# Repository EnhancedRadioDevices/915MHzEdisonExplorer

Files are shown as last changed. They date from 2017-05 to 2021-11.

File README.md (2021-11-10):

# 915MHz RF Explorer block

This Edison Block makes use of a TI CC1110 RF transciever to allow a connected Edison to communicate on the 915MHz band. It is also capable of transmitting at 868MHz (a small antenna alteration will make it much more efficient at that band).

The 915MHz Edison Explorer Block allows an Intel Edison to serve as a bridge from WiFi or Bluetooth to a 915MHz protocol, such as Z-wave, Zigbee, or other manufacturer specific protocols.

# Using these files

The files in this repo are for the 915MHz Explorer hardware. To open them, you'll need KiCAD:

- http://kicad.org/

It may also be helpful to use these libraries:

- https://github.com/mogar/KiCAD_libs

# Applications

For use with Z-wave, 6LowPan, etc.

For Smart Meters, see Wireless-M bus: http://www.ti.com/tool/wmbus

# Supporting Software

For the firmware that goes on the CC1110 itself, see:

- https://github.com/EnhancedRadioDevices/subg_rfspy

For the software that runs on the Edison to communicate with the CC1110, see :

- https://github.com/EnhancedRadioDevices/spi_serial

We also have an RFCat port available

- https://github.com/EnhancedRadioDevices/rfcat

# Acquiring hardware

The Explorer block is currently for sale:

- https://enhanced-radio-devices.myshopify.com/collections/900mhz-explorer-block

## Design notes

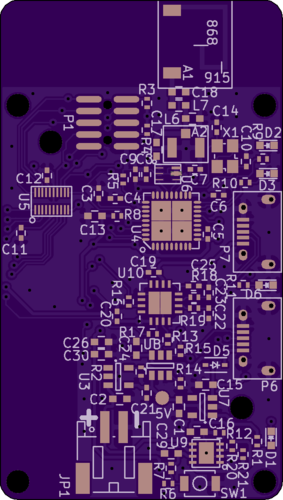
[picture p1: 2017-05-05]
EdisonBlock_915MHz_fab/EdisonBlock_915MHz_bottom.png

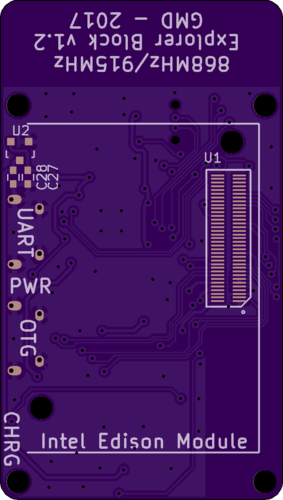
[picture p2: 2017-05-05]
EdisonBlock_915MHz_fab/EdisonBlock_915MHz_top.png

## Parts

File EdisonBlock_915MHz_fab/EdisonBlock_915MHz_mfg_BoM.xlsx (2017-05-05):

Id | Designator | Package | Quantity | Description | Supplier | Part Number
1 | A1 | 0915AT43A0026E | 1 | 0915AT43A0026E | DigiKey | 712-1535-1-ND
2 | A2 | 1909763-1 | 1 | 1909763-1 | DigiKey | A118077CT-ND
3 | C10,C14 | C_0402 | 2 | 18p | DigiKey | 490-5858-1-ND
4 | C13,C1,C2,C15,C16,C24,C26,C29,C30 | C_0603 | 9 | 4.7u | DigiKey | 1276-1045-6-ND
5 | C17 | C_0603 | 1 | 100p | DigiKey | 720-1325-1-ND
6 | C18 | C_0603 | 1 | 0.5p | DigiKey | 1276-1818-1-ND
7 | C22,C23 | C_0402 | 2 | 47p | DigiKey | 490-6241-1-ND
8 | C27,C28 | C_0603 | 2 | DNP
9 | C3 | C_0402 | 1 | 1u | DigiKey | 490-3890-1-ND
10 | C4,C5,C11,C12,C19,C20,C21,C25 | C_0402 | 8 | 0.1u | DigiKey | 490-6328-1-ND
11 | C6,C8 | C_0402 | 2 | 10n | DigiKey | 490-4516-1-ND
12 | C7 | C_0402 | 1 | 2p2 | DigiKey | 490-5932-1-ND
13 | C9 | C_0402 | 1 | 220p | DigiKey | 490-1293-1-ND
14 | D1,D2,D6 | LED_0603 | 3 | RED | DigiKey | 160-1436-1-ND
15 | D3 | LED_0603 | 1 | GREEN | DigiKey | 160-1446-2-ND
16 | D5 | SOD-323 | 1 | DNP
17 | JP1 | JST_ACH_BM02B-ACHSS_02x1.20mm_Angled | 1 | M02JST-PTH-2 | DigiKey | 455-1749-1-ND
18 | L6 | L_0603 | 1 | 4.7n | DigiKey | 490-1162-1-ND
19 | L7 | L_0603 | 1 | 10n | DigiKey | 490-1169-1-ND
20 | P1 | M05x2_FTSH_SMT | 1 | DNP | DigiKey | 609-3695-1-ND
21 | P7,P6 | USB_Micro-B | 2 | USB | DigiKey | 609-4618-1-ND
22 | PCB1 | NA | 1 | EdisonBlock_915MHz PCB | PCB Unlimited
23 | R1,R9,R10,R11 | R_0402 | 4 | 330 | DigiKey | 311-330JRCT-ND
24 | R6,R13 | R_0402 | 2 | 287 | DigiKey | YAG3089CT-ND
25 | R14 | R_0402 | 1 | 100k | DigiKey | 311-100KLRCT-ND
26 | R16,R17 | R_0402 | 2 | 100 | DigiKey | 311-100LRCT-ND
27 | R18,R19 | R_0402 | 2 | 27 | DigiKey | 311-27JRCT-ND
28 | R2 | R_0402 | 1 | 2.0k | DigiKey | 311-2.0KJRCT-ND
29 | R3,R4 | R_0402 | 2 | DNP
30 | R5 | R_0402 | 1 | 56k | DigiKey | 311-56KJRCT-ND
31 | R7,R8,R15,R20 | R_0402 | 4 | 10k | DigiKey | 311-10KJRCT-ND
32 | R12 | R_0402 | 1 | 698 | DigiKey | YAG3215CT-ND
33 | R21 | R_0402 | 1 | 3k | DigiKey | 311-3.0KJRCT-ND
34 | SW1 | SW_SPST_B3U-1000P | 1 | B3U-1000P | DigiKey | SW1020CT-ND
35 | U1 | DF40HC(3.0)-70DS | 1 | EdisonConnector | DigiKey | H124603CT-ND
36 | U10 | QFN-16-1EP_4x4mm_Pitch0.65mm | 1 | FT230X | DigiKey | 768-1130-1-ND
37 | U2 | SOT-23 | 1 | DNP | NA | NA
38 | U3 | SOT-23-5 | 1 | MCP73831 | DigiKey | MCP73831T-2ATI/OTDKR-ND
39 | U4 | QFN-36-1EP_6x6mm_Pitch0.5mm | 1 | CC1110 | DigiKey | 296-38889-1-ND
40 | U5 | UFDFN-20_4x2mm_Pitch0.4mm | 1 | TXB0108-DFN20 | DigiKey | 296-27217-1-ND
41 | U6 | 0915BM15A0001 | 1 | 0915BM15A0001 | DigiKey | 712-1541-1-ND
42 | U7 | SOT-23-5 | 1 | AP7365 | DigiKey | AP7365-39WG-7DICT-ND
43 | U8 | SOT-23-6 | 1 | MIC2039AY | DigiKey | 576-4145-1-ND
44 | U9 | TPS2113A | 1 | TPS2113ADRBT | DigiKey | 296-27373-1-ND
45 | X1 | Crystal_4-SMD_TXC-7V | 1 | 24MHz | DigiKey | 887-2580-1-ND

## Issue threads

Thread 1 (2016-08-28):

Suggestion: UART port

sulkaharo, 2016-08-28:
If I understood correctly, the board uses the SPI to talk to the Edison. Having the second UART port exposed on the board would be huge for adding further features, such as connecting a Wixel for 2.4GHz band capture. Would this be in the scope for this board, or would you suggest for example sandwiching this with the Sparkfun UART board?

mogar, 2016-08-28:
Do you mean from the Edison to the CC1110? Yes, that's a SPI port. There are not really any GPIO broken out from the Edison that aren't already used on the board, so if you want to use a UART with an external board like the Wixel I recommend using another Edison Block.

That said, the Edison's UART and OTG are exposed through USB connectors. It would probably be possible to connect the OTG port to something like the wixel. I would also think that it should be possible to use the Edison's own 2.4GHz radio to do a capture in that band, but I haven't looked into it.

mogar, 2016-09-15:
We could potentially break out some GPIO or another UART to a header for this purpose. I'll look into it for the next revision.

oskarpearson, 2016-09-15:
@sulkaharo Are the devices we're thinking of using in this way all 3.3v?

If so, would we also need to break out a ground and 3.3v points to supply power to the UART device?

Also, would the devices require flow control (RTS/CTS)?

If so it'd mean breaking out 6 pins: TX, RX, RTS, CTS, +3.3v, GND - is that correct? Would these require through-hole soldering connectors?

mogar, 2016-09-15:
The Edison has two UARTS. UART2 is used for the USB-UART converter. UART1 could be used for this, and it does have flow control.

We could use a tiny connector for these so that people wouldn't have to solder them. I don't expect we'd have a ton of space, so standard 0.1" headers won't work.

Given how tight the routing is getting on the Explorer board, it might be worth having a second mezzanine board between the Edison and the Explorer that actually breaks out the pins. That would make the whole thing about 5mm thicker, but would be easier to connect ti.

sulkaharo, 2016-09-15:
I'm thinking of the Wixel, which should work fine with 3.3. Exposing 1.8v level would allow hooking a logic level shifter in the mix?

mogar, 2016-09-15:
The Edison pins are 1.8V by default, so we'd need to either throw another level shifter on the board or use one off-board to communicate with the Wixel. At this point, I'm thinking that this is going to effect board size too much, and it might make sense to just use a second Edison Block to access those pins.

mogar, 2016-10-11:
There's not really space on the board for another level shifter. I'm going to say that we won't be adding a second UART, and if you want one I recommend using one of SparkFun's adapter blocks between the Explorer and the Edison.

Closed 2016-10-11.

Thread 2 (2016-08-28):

Plugging/unplugging power power-cycles the Edison

scottleibrand, 2016-08-28:
When the power switch is ON, plugging in microUSB power (to either the UART or OTG microUSB port) power-cycles the Edison.

It would be *much* preferred if we could have the Edison stay powered while transitioning from battery power to charging.  I would even give up the hardware power switch entirely for that if necessary.

mogar, 2016-08-28:
This looks like it won't be easy to fix on the current board rev, but it should be easy to fix for the next hardware rev.

mogar, 2016-08-28:
With the current hardware rev, it's possible to cut a trace that will cause the board to not accept power from USB. USB can still charge the battery, but it can't turn on the Edison or CC1110. This fixes the power-cycle issue at the expense of not being able to use it without a battery.

If you get me your hardware, I can make this modification for you. I'll also post some notes about how to do it next week.

scottleibrand, 2016-08-29:
Ok, thanks.  Definitely something we should fix in future versions.  I'll probably wait until we figure out antenna tuning before modifying this board.

mogar, 2016-09-15:
For the next hardware rev, we're going to switch the inputs (battery and USB power) to U9. We're also going to replace the 4V LDO that generates USB power to the Edison with something that can handle more current (probably the AP7365).

scottleibrand, 2016-09-28:
I've now got both Explorer boards (one with the trace cut, one without) fully up and looping well on battery power, but have been seeing them powercycle almost constantly (within minutes of boot) when plugged into USB.  Was the trace cut supposed to fix that, or is that an unavoidable issue until we get the 2nd gen hardware with the AP7365 or similar?

Will it be practical to upgrade the 4V LDO on existing boards, or would it be better to just use them as dev boards and replace them with the newer ones for production use?

mogar, 2016-09-28:
The cut trace should have fixed that issue. I'd like to take a look at your
hardware and see what's going on, since I've had on problems with the cut
trace on four different boards I've done it to.

On the topic of the LDO upgrade: I'd like to upgrade your hardware and have
you test it out. Long term, I recommend getting the newer hardware after
the fix is integrated for the stability. The upgrade is not going to be as
robust as a full standard circuit board.

On Tue, Sep 27, 2016 at 7:03 PM, Scott Leibrand <notifications@github.com>
wrote:

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

mogar, 2016-10-11:
The design has been adapted and the next revision won't have this bug.

Closed 2016-10-11.

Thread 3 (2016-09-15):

USB OTG

scottleibrand, 2016-09-15:
Has USB OTG been tested?  I can't seem to get our board to recognize a Dexcom (or a Kindle) connected over USB OTG.  `lsusb` does detect the OTG cable itself, though, as a USB 2 and a USB 3 hub.  Wondering if there may be some power draw limitations like the Intel breakout board has?

mogar, 2016-09-15:
USB OTG hadn't been tested yet.

There is no 5v regulator on the board, so if you connect a device that
needs external power then it won't work. Have you tried a powered hub?

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

mogar, 2016-09-15:
If we reverse D5, then the USB OTG port can be powered from the UART port. This would allow you to plug the OTG device directly into the board without using a powered hub.

scottleibrand, 2016-09-15:
So that would require external USB power then?  Do I correctly assume that powering the USB OTG port from a JST-connected lipo would be infeasible?  Or is that an option too?

Pass-through USB power from UART to OTG port would probably be OK: we'd just need to plug in an external USB battery for offline mode, but if we're plugging in a USB device we're already giving up on the tiny form factor, so that's not as big a deal.

mogar, 2016-09-15:
Powering the USB OTG port from a connected LiPo is possible, but requires additional circuitry to boost the voltage to ~5.2V. That will add size, cost, and potentially thermal issues. Could be worth it though.

I think using an external battery for passthrough from the UART to the OTG port is probably the best way to go.

PieterGit, 2016-09-30:
Does a Dexcom G4 require a USB OTG connection to be connected to the Explorer Board or is it possible to use a Dexcom G4 with a USB connection with the Explorer Board?

Being able to use wire up a Dexcom G4 (instead of using blueotooth) would be a really nice feature.

scottleibrand, 2016-09-30:
I believe the next round of hardware will support connecting the Dexcom G4
over USB OTG, but only if you also plug in external USB power to the UART
microUSB port.

One of the next things on my list is to see if I can get openxshareble
working with oref0-setup on the Explorer board with jubilinux...

Does that answer your question?  I'm not quite clear what you mean by "require
a USB OTG connection" vs. "use a Dexcom G4 with a USB connection".

PieterGit, 2016-09-30:
I mean: can I use the Dexcom G4 wired by USB/USB OTG with the Explorer board. Most bluetooth connection tend to be really pain in the ass to setup, and bluetooth libraries on Linux seem to have several quirks.

So I would prefer to use a wired USB connection between the Dexcom G4 receiver and the Explorer board. I thought this was a "regular" USB-connection and thought USB OTG was a different thing.

I think the form factor of Dexcom receiver and a explorer board and lipo battery is still fairly acceptable, so I would prefer a way to power a rig like that by using only one battery somehow. Will that be possible?

scottleibrand, 2016-09-30:
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

Yeah.  I'll be trying to figure out that setup and iron out the BT quirks,
but we'll see.

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

USB OTG is simply the way you do "regular USB" over a microUSB port.

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

Unfortunately it's not possible to power the USB OTG port from a lipo
without a 5v upshifter, which would require significant board redesign and
expansion.  You will, however, be able to remove the lipo if you're
powering the Explorer board over USB. Or you can have a smaller USB battery
and keep the lipo.

PieterGit, 2016-09-30:
Thanks for clarifying USB OTG. I assume a 5v upshifter is similar to a AdaFruit PowerBooster module.
Would it be possible to enhance the design of the board so that a user can add a upshifter/PowerBooster module as an extension so that the rig can be powered by one battery.

Or am I right that a LIPO connected to a AdaFruit PowerBooster 1000 module, that powers the Explorer board over USB makes it possible to connect the Dexcom G4 with USB OTG (perhaps also connecting the 5V to the UART/USB OTG port).

This would probably also improve battery life a bit (using wired connection instead of Bluetooth). But main reasons for me for this use case will be easier setup and improved reliability. If you guys can think of ways to integrate this, or make it easier to integrate this as an add-on, I would be very very happy.

scottleibrand, 2016-09-30:
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

Yes, or a similar chip onboard.

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

Yes, but we decided not to do that due to size constraints and potential
extra power drain.  If you want a larger board with that built-in (as well
as built-in wiring for wixel), the RiledUp board might be a good option.

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

Perhaps, although I'm not sure why you would bother with lipo + powerboost
rather than just getting a 5V USB battery.

> This would probably also improve battery life a bit (using wired
> connection instead of Bluetooth).
>

Unlikely: the USB with 5V upconversion drains significantly more power than
Bluetooth does, even if you turn of the Dexcom's charging feature.

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

Yeah, that will likely be a common use case if we can't get openxshareble
reliable enough.  I'm working on that right now, so I'll let you know how
it goes.

PieterGit, 2016-10-04:
I believe a lot of (non US) Dexcom G4 users don't have the possibility to use the Share / bluetooth function. I think the hardware supports bluetooth, but the receiver firmware disables the share/bluetooth afaict. A way to wire up the Dexcom to the Explorer board somehow would really be an essential feature for those users.

scottleibrand, 2016-10-04:
I'll be meeting up with Morgan tomorrow to test using a Dexcom over microUSB OTG (with external 5V USB power on the other microUSB port).

scottleibrand, 2016-10-06:
We tested that the new Edison Explorer board can read BG from a Dexcom connected over USB, if it also has a USB battery providing 5V power on the other USB port. Not the most compact setup to carry an external battery, but allows for completely offline looping without reliance on openxshareble.

Closed 2016-10-06.

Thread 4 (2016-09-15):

Optimize antenna performance

mogar, 2016-09-15:
The best antenna lengths have been determined for 868MHz and 915MHz. Make it easy for users to adapt the board for their chosen frequency. It also probably makes sense to make the default length optimal for 868MHz.

mogar, 2016-10-11:
The silk layer of the next revision has been adapted to show the optimal antenna lengths.

Closed 2016-10-11.

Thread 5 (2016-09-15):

Reset button for Edison

mogar, 2016-09-15:
It would be good to have a reset button for the Edison, so that it doesn't always get turned off with a hard power cycle.

oskarpearson, 2016-09-15:
Technical info:
http://download.intel.com/support/edison/sb/edisonbreakout_hg_331190006.pdf lists the button as being J18 - pin 3.

http://download.intel.com/support/edison/sb/edisonmodule_hg_331189004.pdf page 14 lists pin 17 as "power/sleep button input (active low)"

mogar, 2016-10-11:
Including on next revision.

Closed 2016-10-11.

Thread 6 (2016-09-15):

UART doesn't function correctly if plugged in before power is applied to board

mogar, 2016-09-15:
If the UART USB cable is plugged in before the Edison is powered, the UART malfunctions. This is most likely due to a problem with the reset pin on the UART IC (U10). That should probably be pulled up to USB voltage, not Edison voltage.

mogar, 2016-10-11:
The reset pin of the UART chip has been connected to the UART ICs own 3.3V regulator in the next revision. This should fix the issue.

Closed 2016-10-11.

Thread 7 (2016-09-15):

Break out points for 3.3v / GND

oskarpearson, 2016-09-15:
It may be useful to break out the 3.3v and ground outputs for powering other devices. These could through-hole connectors, or simple surface-pads that are suitable for soldering.

I'm separating this from https://github.com/EnhancedRadioDevices/915MHzEdisonExplorer/issues/1 since it may be a separate issue.

mogar, 2016-10-11:
The space constraints on the board make this a bit tough to do in a way that beginning solderers can handle. The next revision won't have the SMT header populated for the CC debugger, and there's a 3.3V and GND pad on that footprint. You could use those if you really needed this. Think that'll be sufficient?

oskarpearson, 2016-10-11:
That's a-ok with me. Thanks!

Closed 2016-10-11.

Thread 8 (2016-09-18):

How to reset subg_rfspy on errors

scottleibrand, 2016-09-18:
I just flashed Yocto and Ubilinux onto two different Edisons using the Explorer board, and in both cases when I got everything installed the subg_rfspy firmware did not respond correctly, but rather gave me lots of �'s.  Flashing spi1_alt2_EDISON_EXPLORER_US_STDLOC.hex fixed it both times.

Is there anything we can do to prevent the OS flash process from erasing/corrupting the subg_rfspy firmware?

```
root@edison-eb ~/src/915MHzEdisonExplorer_SW # python ExplorerTest.py
������������������������������������������������������������������������������������������������������������������������������������������������������������������������������������������������������������������������������������������������������������������������������������������������������������������������������������������������������������������������������������������������������������������������������������������������������������������������������������������������������������������������������
������������������������������������������������������������������������������������������������������������������������������������������������������������������������������������������������������������������������������������������������������������������������������������������������������������������������������������������������������������������������������������������������������������������������������������������������������������������������������������������������������������������������������
������������������������������������������������������������������������������������������������������������������������������������������������������������������������������������������������������������������������������������������������������������������������������������������������������������������������������������������������������������������������������������������������������������������������������������������������������������������������������������������������������������������������������
```

mogar, 2016-09-18:
How did you flash the Edisons?

I've flashed yocto onto Edisons via the Explorer board about a dozen times
and never had it corrupt the firmware. I think it's more likely that
subg_rfspy got into a bad state and needed to be reset. The reset that was
in spi_serial was there to take care of such issues, and it may be that
calling the reset function would have fixed your issue.

It's already on the subg_rfspy todo list to fix the communications
protocol. If the wrong bytes are sent, it can put it into a state where the
CC1110 expects more bits than the Edison thinks it should send. I'm going
to put in a timeout to keep this from permanently messing things up.

On Sun, Sep 18, 2016 at 1:24 AM, Scott Leibrand <notifications@github.com>
wrote:

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

scottleibrand, 2016-09-18:
Interestingly, a full halt and power-cycle didn't recover it.

What would be the command to run the reset manually now that we've moved it to its own function? I'll give that a try if I see this again after the next flash.

scottleibrand, 2016-09-18:
Yep, looks like that was it.  Had it happen again after powering it on (with no flashing involved), and was able to do ` python -c "import spi_serial; s=spi_serial.SpiSerial(); s.reset()"` to reset it.

For now, I just added that to my crontab to run if wait-for-silence gets stuck retrying for 10m.  Wondering if there's a better way to
```

mogar, 2016-09-18:
Ultimately, the fix for this needs to be in subg_rfspy.

Short term, I recommend checking subg_rfspy status before doing anything
major. If you don't get back ok, then you can reset.

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

scottleibrand, 2016-09-18:
Ok, will do, thx.

Closed 2016-09-18.

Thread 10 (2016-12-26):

Power and OTG

glenrob1940, 2016-12-26:
Using the board with openAPS.  Attempting to go offline using OTG is flaky.  With a USB Battery/Charger connected to the UART micro USB connecting a CGM receiver with an OTG adapter cable to the OTG micro USB succeeds about 50% of the time.  When it fails, the device has not been recognized by jubilinux.  A similar issue occurs with the Intel Breakout Board if only using USB power, however with Vbat applied (>5V) the issue does not occur in that setup.  Is it possible to connect an external battery to the explorer board, and what is the allowable voltage range and pins (D?) to use.  Has OTG testing been done with just USB power applied through the UART connection?

scottleibrand, 2016-12-26:
Are you asking about connecting an external battery via direct solder points on the board?  We've supplied 5V power via the microUSB UART port, and confirmed that OTG can be used, but we've also sen flakiness.  I've seen the Dexcom charging icon light up and `lsusb` still fail, which seemed to me to indicate OTG flakiness rather than power, but I suppose a direct 5V connection would be a good way to test that.  @mogar do you know if that's possible, and if so which holes we'd want to wire 5V to?

glenrob1940, 2016-12-27:
Yes, that is what I am asking

mogar, 2016-12-27:
There aren't any test-points on the board for 5V, but if you're handy with soldering then you'll be able to do it. You could solder a 5V connection to the cathode of D5 (right next to the OTG USB port). That would allow you to power the OTG device directly.

Another thing you could do is to use the UART USB jack to apply power, but then just cut the USB cable and supply your own 5V source.

glenrob1940, 2016-12-27:
Hi Scott,

I was asking about that, but also whether or not we could use a higher
voltage external power source via direct solder points on the board.
The Intel breakout board allows 7-15 Volts on it's external power input
(which is down-converted to 5 volts).  When I run my edison/intel
breakout board, I plug in a 9V or 12 V external power source. I also
have a LIPO, but it of course can't power USB. A USB charger/battery can
be plugged into the micro USB UART port, but having another wired in
power point would allow other battery choices, and might cure the OTG
flakiness.

Glen

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

mogar, 2016-12-27:
The maximum voltage on the 5V rail is 5.5V. Higher than that could damage the UART-USB converter.

If you apply 5V directly to the cathode of D5, then you'll be powering the OTG device with exactly 5V (and not have the diode drop to account for).

glenrob1940, 2016-12-27:
Hi Morgan,

I also replied to Scott.  One of the (not articulated) questions I had
was whether it was possible to apply higher voltage.  The Intel mini
breakout board has a 7-15V external power input which it down-converts
to 5V.  I did not know if your board had similar external power input.
I will investigate implementing one of your two suggestions.  Thanks,

Glen

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

glenrob1940, 2016-12-27:
Okay.  I will keep that in mind.

Glen

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

Closed 2017-01-08.

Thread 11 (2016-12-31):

LED Descriptions

jaylagorio, 2016-12-31:
Is there documentation describing what each of the LEDs indicate? Are any of them controllable programmatically?

scottleibrand, 2016-12-31:
I believe the two LEDs next to each other are controllable by the subg_rfspy firmware.  Not sure whether the power or charging LEDs are controllable in software.

mogar, 2017-01-02:
The two LEDs are controlled by whatever firmware is on the CC1110. As @scottleibrand mentioned, the default is subg_rfspy. You can find that software here: https://github.com/EnhancedRadioDevices/subg_rfspy

Note that you can override the default LED operation by sending a command from the Edison to turn the LEDs on or off. The readme at the subg_rfspy repo explains the command for controlling LEDs from the Edison.

By default, the LEDs blink to indicate that the board is reset, but that's it. They were used for debugging purposes, and if you look through the code you'll see where commands to turn the LEDs on or off have been commented out. We turned them all off except in a reset to save power.

jaylagorio, 2017-01-02:
This is great, thank you!

Closed 2017-01-02.

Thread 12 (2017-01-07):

Reversed LiPo fries the charging circuit

sulkaharo, 2017-01-07:
Just discovered I'd been shipped JST connectors with reversed current markings: a battery was connected with reversed ground/hot for around one second, after which smoke appeared and the Edison now crashes if a batter is connected to the Explorer. USB power seems to work. Might be worth checking if a future iteration of the board can include a reverse current/battery protection circuit.

mogar, 2017-01-08:
Thanks for the report. I'll add this to the list of improvements to make for the next revision. We'll probably do another revision in the second half of this year.

bmammon, 2017-06-15:
I think this might be my problem.. @sulkaharo, when you connected the battery to the Explorer, did the red power light keep blinking? When connected to USB power, everything runs fine so I think current was reversed. Is there a way to fix this? @mogar

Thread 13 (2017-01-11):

Alpha board antenna orientation

cjo20, 2017-01-11:
I've been looking in to some comms issues, and I noticed that the orientation of the chip antenna on my alpha board doesn't seem to match the datasheet / production boards (assuming this is the correct data sheet: http://www.johansontechnology.com/datasheets/antennas/0915AT43A0026.pdf)

The brown mark is towards the outside edge of my board.

I am managing to get comms working, but it seems to have intermittent issues with timeouts or bad CRCs. Is it possible the antenna orientation is contributing to the problem? Would it be worth me trying to turn it round?

I have trimmed the antenna trace as suggested on the wiki page for 868MHz.

mogar, 2017-01-13:
You're correct that the antenna is installed backwards on the alpha boards. My testing shows that this doesn't have much of an effect. I doubt this is causing your issue. If you have a soldering iron, it shouldn't be too hard to swap the antenna.

One way you could test this is to place the Explorer and your other device right next to each other. If they still have problems, then it's most likely due to a protocol issue instead of signal strength.

Is this related to your testing of the SW issue? https://github.com/EnhancedRadioDevices/915MHzEdisonExplorer_SW/issues/9

cjo20, 2017-01-13:
The thing that prompted this question is READ_PACKET timing out for no apparent reason. Increasing the timeout to 1 second doesn't improve the issue, so I'm still working on finding it. I do still get the issue when they're right next to each other. It's a bit random as to when it happens, so I'm struggling to track it down.

I seem to have pretty much completely eliminated the other issue with some software changes. I'm waiting for comments / review from others before saying that for sure that the issue can be managed in mmeowlink.

Closed 2017-01-24.

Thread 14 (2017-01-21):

USB OTG and Dexcom G4 Receivers

jaylagorio, 2017-01-21:
I've been using this board off and on for a month or so and have previously been able to communicate with the G4 receiver over USB using a USB OTG cable and external USB power source. Today I have been unable to communicate with the device. My quick test involves running `openaps use cgm iter_glucose 1`

The G4 receiver shows that it's plugged in with the icon in the corner and the USB OTG cable is connected to the OTG port on the Explorer board. `lsusb` returns error -99 and `/dev/ttyACM0` doesn't show up on the Edison like it does on a Pi 2.

@scottleibrand Mentioned a hardware issue being looked into - unless there is something else I can check to see why the receiver isn't being recognized?

mogar, 2017-01-24:
@jaylagorio We have identified a bug in the current hardware version that can make USB OTG function sporadically. My only suggestion for you now is to try unplugging your USB OTG device, rebooting, and then plugging back in. That may fix it. We're working on a better fix for this.

If you'd like, there's a quick hardware modification that should make this more stable. It requires cutting a single trace. Contact us by email if you want help with that.

glenrob1940, 2017-01-24:
I would like info on cutting the trace.

Glen Robinson     (@glenrob1940)

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

Kdisimone, 2017-01-24:
Yes please +1

PieterGit, 2017-01-24:
Please give me more information on the suggested hardware fix @pietergit

scottleibrand, 2017-01-24:
@mogar comment above asked you to email him, so you might want to do that...

jaylagorio, 2017-01-24:
Yeah, I emailed sales@enhancedradio.com

mogar, 2017-01-24:
Here are the instructions for the trace-cut: https://github.com/EnhancedRadioDevices/915MHzEdisonExplorer/wiki#usb-otg-flakiness

This could be a difficult cut to make if you don't have a microscope and experience with PCBs. Anyone who would like to ship their board back to us for us to do it is welcome to. Just email us beforehand at sales@enhancedradio.com

scottleibrand, 2017-01-26:
@mogar just confirmed that this is indeed a hardware issue.  (Specifically, U8 needs to be a MIC2039A instead of a MIC2039B.) Future Explorer boards will be produced using that part, and should be much more reliable for OTG use.  The trace-cut described above should work well for any existing boards.  The only side effect of that cut would be that, because it bridges the 5V power between the two microUSB ports, plugging two different power supplies into the same Edison at the same time should be avoided if possible.  If it does occur, one of the devices (particularly if it's a computer) may disable its USB port temporarily due to the unexpected voltage.  It shouldn't damage anything, though, and plugging both microUSB ports into the same device (i.e. for flashing) should work fine.

I have been testing a board with the trace-cut, and have had much more reliable OTG than on other boards.  I have not noticed any issues when plugging in wall power to one microUSB port and a USB battery to the other (briefly, while swapping power sources).  I have not plugged into my computer's USB port while powering the other microUSB port, and do not intend to do so.

scottleibrand, 2017-01-28:
For those of you who've done the trace cut for USB OTG reliability: have any of you tried re-flashing the Edison since doing so?  I'm not able to see the Edison over the trace-cut Explorer board's OTG port, and therefore can't get it to re-flash.  Wondering if that's an inevitable side-effect of the trace cut, or something specific to my setup.  If you'd like to test without re-flashing, you can plug the board in to your Mac using the OTG port, and then reboot or unplug it, and you should get the Disk Not Ejected Properly warning if OTG is working.  If you've done the trace cut, can you give that a try?

jaylagorio, 2017-01-28:
I've done the trace cut and now have a successful loop! However, Morgan explained the following about how/why this works: "The wrong part was used for the OTG power switch, so when you plug in OTG it turns power off and not on. Straightforward to fix, but a bit tough to implement a fix for everyone's current board. You could either replace the part or do the trace cut, and either would work."

This leads me to believe that we've irreversibly made it so you can't flash it since we've reversed the way the power works by cutting the trace. At @scottleibrand's suggestion I did this:
1. Edison/Explorer with Lipo already powered on and logged into SSH, connecting OTG port to PC USB
2. shutdown -r now over SSH
3. Absolutely no movement of any kind in Device Management, not even a quick change

So unless you have a second board you can use to flash the Edison you might not want to do this in case you have to reflash.

mogar, 2017-01-29:
Thanks for the thorough reports, @jaylagorio and @scottleibrand. You are both correct that the trace cut causes the Edison to always be in OTG mode, and never be in peripheral mode. That means that the Explorer can't be used to flash the Edison after the trace cut is made.

One further note is that there's also a design flaw on the PCB for these boards. Just replacing the incorrect part won't fix everything. Right now it's a choice between OTG always, or flakey behavior where it only sometimes works with OTG.

I have a new set of boards on order that will have this problem fixed. Those should come in by the end of February.

jaylagorio, 2017-01-29:
I think we've thoroughly documented the issue, the workaround (trace cut), the workaround side effects, the solution (design fix), and the expected time to market for the solution. If everyone else is happy I can close this. Anyone agree?

Kdisimone, 2017-02-08:
agree

Closed 2017-02-10.

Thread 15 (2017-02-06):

serial ports on cc111x

dclovesdc1, 2017-02-06:
working with edison, explorer and pingrf sw. My understanding is that when connecting to edison, spi would be the primary communication path. Are the serial ports on cc111x wired to communicate with edison in addition? Trying to see what would be a good way to print out debug prints from firmware. Thanks.

mogar, 2017-02-07:
If you're using the subg_rfspy firmware as a basis, you can use the spi_serial library for debug print statements. You'll just have to poll the spi bus using spi_serial on the Edison.

The SPI interface on the CC1110 is USART1, which can also be used as a UART if you want. UART1/UART uses P1.6 and P1.7 as TX and RX, respectively. If you want to use UART0 instead, USART0/UART uses P1.4 and P1.5 as TX and RX, respectively.

dclovesdc1, 2017-02-07:
Thanks for the info. I am using pingrf. I am trying to see if I could get the spi running on USART1 (alt2) while running UART to print out debugging information. So, it seems like I could use UART0, which is also alt2 configuration.
It looks like another option would be to run UART0 at alt2 & UART1 at alt2.
Can you please let me know if I am interpreting what you are saying correct?
Thanks.

      From: Morgan Redfield <notifications@github.com>
 To: EnhancedRadioDevices/915MHzEdisonExplorer <915MHzEdisonExplorer@noreply.github.com>
Cc: dclovesdc1 <dclovesdc@sbcglobal.net>; Author <author@noreply.github.com>
 Sent: Monday, February 6, 2017 8:12 PM
 Subject: Re: [EnhancedRadioDevices/915MHzEdisonExplorer] serial ports on cc111x (#15)

If you're using the subg_rfspy firmware as a basis, you can use the spi_serial library for debug print statements. You'll just have to poll the spi bus using spi_serial on the Edison.The SPI interface on the CC1110 is USART1, which can also be used as a UART if you want. UART1/UART uses P1.6 and P1.7 as TX and RX, respectively. If you want to use UART0 instead, USART0/UART uses P1.4 and P1.5 as TX and RX, respectively.—
You are receiving this because you authored the thread.
Reply to this email directly, view it on GitHub, or mute the thread.

dclovesdc1, 2017-02-07:
one more thing I forgot to ask, if I use usart0/uart & usart1/uart configuration, which device would that be associated on the edison? Thanks.

      From: Morgan Redfield <notifications@github.com>
 To: EnhancedRadioDevices/915MHzEdisonExplorer <915MHzEdisonExplorer@noreply.github.com>
Cc: dclovesdc1 <dclovesdc@sbcglobal.net>; Author <author@noreply.github.com>
 Sent: Monday, February 6, 2017 8:12 PM
 Subject: Re: [EnhancedRadioDevices/915MHzEdisonExplorer] serial ports on cc111x (#15)

If you're using the subg_rfspy firmware as a basis, you can use the spi_serial library for debug print statements. You'll just have to poll the spi bus using spi_serial on the Edison.The SPI interface on the CC1110 is USART1, which can also be used as a UART if you want. UART1/UART uses P1.6 and P1.7 as TX and RX, respectively. If you want to use UART0 instead, USART0/UART uses P1.4 and P1.5 as TX and RX, respectively.—
You are receiving this because you authored the thread.
Reply to this email directly, view it on GitHub, or mute the thread.

mogar, 2017-02-08:
On the Edison, the pins those are connected to are set up as SPI. You could implement a software serial library to handle them though. For Edison pin information, check out the mraa guide here: https://iotdk.intel.com/docs/master/mraa/edison.html

You could also try getting spi_serial working with pingrf. Check out the spi1_alt2 code in subg_rfspy to see how that works. Then you could use the pingrf firmware with our spi_serial Edison library.
https://github.com/EnhancedRadioDevices/subg_rfspy/tree/master/spi1_alt2

dclovesdc1, 2017-02-08:
Thanks for the info. I haven't worked with mraa before. So, I'll need to look into it.
working with spi1_alt2 mode for the general communication is fine. but i am also interested in using the serial port concurrently to print out debug information from the firmware. That is actually how pingrf works today (usb for communication & uart1 for debug, usart0 for communication & uart1 for debug, etc) Any examples that you can suggest to enable uart0 for debug print while using spi1_alt2 example for the general communication? Thanks.

      From: Morgan Redfield <notifications@github.com>
 To: EnhancedRadioDevices/915MHzEdisonExplorer <915MHzEdisonExplorer@noreply.github.com>
Cc: dclovesdc1 <dclovesdc@sbcglobal.net>; Author <author@noreply.github.com>
 Sent: Tuesday, February 7, 2017 9:47 PM
 Subject: Re: [EnhancedRadioDevices/915MHzEdisonExplorer] serial ports on cc111x (#15)

On the Edison, the pins those are connected to are set up as SPI. You could implement a software serial library to handle them though. For Edison pin information, check out the mraa guide here: https://iotdk.intel.com/docs/master/mraa/edison.htmlYou could also try getting spi_serial working with pingrf. Check out the spi1_alt2 code in subg_rfspy to see how that works. Then you could use the pingrf firmware with our spi_serial Edison library.
https://github.com/EnhancedRadioDevices/subg_rfspy/tree/master/spi1_alt2—
You are receiving this because you authored the thread.
Reply to this email directly, view it on GitHub, or mute the thread.

mogar, 2017-02-10:
Unfortunately, the serial port and the SPI port use the same pins. You'll have to choose one or the other. We can look into opening up the other UART on the next hardware revision.

dclovesdc1, 2017-02-11:
Ok. Any examples or suggestion on how to choose the serial port instead of spi? Thanks.

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

dclovesdc1, 2017-02-14:
Thanks for the info. Do you know which /dev/?? will be connected to the serial port if I enable serial port only on cc1110? Thanks.

      From: Morgan Redfield <notifications@github.com>
 To: EnhancedRadioDevices/915MHzEdisonExplorer <915MHzEdisonExplorer@noreply.github.com>
Cc: dclovesdc1 <dclovesdc@sbcglobal.net>; Author <author@noreply.github.com>
 Sent: Friday, February 10, 2017 11:04 AM
 Subject: Re: [EnhancedRadioDevices/915MHzEdisonExplorer] serial ports on cc111x (#15)

Unfortunately, the serial port and the SPI port use the same pins. You'll have to choose one or the other. We can look into opening up the other UART on the next hardware revision.—
You are receiving this because you authored the thread.
Reply to this email directly, view it on GitHub, or mute the thread.

mogar, 2017-02-20:
The CC1110 comms pins are connected to a SPI port on the Edison. You can interface with those pins as GPIO, but I don't think they have a hardware serial port attached to them. You'd need to write a software serial driver that manages those pins as GPIO. That shouldn't be too tough if you just set up interrupts on the RX pin.

To see how to set the CC1110 comms pins in different modes, take a look at the subg_rfspy source:
https://github.com/EnhancedRadioDevices/subg_rfspy

Specifically, the code in the spi1_alt2 directory sets up the pins as a SPI bus. You can also build the project with uart0 or uart1 enabled. The makefile should show you how to do that.

Take a look at the schematic for pin connections between the CC1110 and the Edison:
https://github.com/EnhancedRadioDevices/915MHzEdisonExplorer/blob/master/EdisonBlock_915MHz_fab/EdisonBlock_915MHz.pdf

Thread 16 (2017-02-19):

problems with USB OTG trace cut

PieterGit, 2017-02-19:
I cut the trace as described on the wiki
https://github.com/EnhancedRadioDevices/915MHzEdisonExplorer/wiki#usb-otg-flakiness
but I still don't get USB working on a Dexcom G4 receiver.

```
# lsusb
unable to initialize libusb: -99
# dmesg | tail
[   80.954248] pmic_ccsm pmic_ccsm: USB ID Detected. Notifying OTG driver
[   81.923003] dwc3-device dwc3-device.1: device suspended; notify OTG
# uname -a
Linux myedison 3.10.17-poky-edison+ #6 SMP PREEMPT Wed Mar 23 21:47:59 EDT 2016 i686 GNU/Linux
```

Does `lsusb` work with other boards or was my cut not deep enough?
Any other things I could try?

PieterGit, 2017-02-19:
Distribution: jubilinux, updated today
Powered with 5V on UART port.

PieterGit, 2017-02-19:
tried it on same explorerboard with other edison with more recent kernel. that works!

# uname -a
Linux myedison 4.8.0-rc4 #3 SMP Mon Sep 5 07:49:17 EDT 2016 i686 i686 i686 GNU/Linux
# lsusb
Bus 002 Device 001: ID 1d6b:0003 Linux Foundation 3.0 root hub
Bus 001 Device 003: ID 22a3:0047
Bus 001 Device 001: ID 1d6b:0002 Linux Foundation 2.0 root hub

Unfortuately communicating with the CC1111 on a newer kernel does not seem to work. Any way to get it working with a linux 3.10 kernel?

mogar, 2017-02-20:
Cutting the trace is a bit of a hack, and doesn't completely fix the problem. I know it works with the recommended Jubilinux image, but I can't guarantee anything else. The next set of Explorer boards have this issue actually fixed.

This may also be an Edison issue. Are you sure that the kernel variant you're using can access the Edison's USB port under normal circumstances? Do you have a different dev-board you can use to test the Edisons?

How come you're not using the standard Jubilinux/MRAA/spi_serial method?

PieterGit, 2017-02-20:
It's the other way around. USB OTG doesn't work with the recommended Jubilinux image for me with an Explorer board with trace cut. But it does work with a 4.8 ubuntu image. That's why I tried to upgrade the kernel, to see if that fixes the USB OTG problem. It did (after the trace cut), but unfortunately the  4.x kernel does not work nicely with the CC1110 https://github.com/EnhancedRadioDevices/915MHzEdisonExplorer/issues/17

mogar, 2017-02-22:
Gotcha. In that case I think your trace cut may not have been complete. I can't say with certainty without seeing your board, but I think that some of your issues may be due to incorrectly modified hardware. The best thing to do at this point is probably to email me directly at sales@enhancedradio.com.

PieterGit, 2017-04-09:
Tracecut was succesfull. The 3.10.17 kernel is not very suitable for using USB subsystem. Better to upgrade the kernel 3.10.98. I can get the Dexcom G4 with USB working with jubilinux 0.1.1 when I append
```
rmmod g_multi
modprobe g_multi
```
to `/etc/rc.local`.

Unfortunately the USB OTG only works after replugging the USB OTG cable on the Explorer board side (not on the dexcom side). Then a `lsusb` will show
```
# lsusb
Bus 002 Device 001: ID 1d6b:0003 Linux Foundation 3.0 root hub
Bus 001 Device 002: ID 22a3:0047
Bus 001 Device 001: ID 1d6b:0002 Linux Foundation 2.0 root hub
```

@mogar or @scottleibrand :
Can the Explorer board detect that the OTG cable is released? I don't understand why pulling the plug at the Dexcom reciever side doesn't work. Is this a hardware issue that has been fixed with the newer Explorerboard revisions described in https://github.com/EnhancedRadioDevices/915MHzEdisonExplorer/issues/14 ?

mogar, 2017-05-05:
Latest hardware revision fixes this issue. Please contact us directly if you continue to have issues with it.

Closed 2017-05-05.

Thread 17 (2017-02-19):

MRRA / PIN23 problem with on Explorerboard non 3.10 kernel

PieterGit, 2017-02-19:
With recent 4.8 and 4.10+ kernels I get problems with accessing the TI-chip on an Explorer board

```
# reset_spi_serial.py
Traceback (most recent call last):
  File "/usr/local/bin/reset_spi_serial.py", line 6, in <module>
    exec(compile(open(__file__).read(), __file__, 'exec'))
  File "/root/src/915MHzEdisonExplorer_SW/spi_serial/scripts/reset_spi_serial.py", line 3, in <module>
    s = spi_serial.SpiSerial()
  File "/root/src/915MHzEdisonExplorer_SW/spi_serial/spi_serial/spi_serial.py", line 7, in __init__
    self.cs0 = m.Gpio(23)
  File "/usr/local/lib/python2.7/dist-packages/mraa.py", line 995, in __init__
    this = _mraa.new_Gpio(pin, owner, raw)
ValueError: Invalid GPIO pin specified
```
I thought it might be a kernel issue, but according to Andy Shev (kernel developper) it's a MRRA or baseboard problem, see https://github.com/andy-shev/linux/issues/8

Questions:
1) Can you explain why pin 23 is used? The python source does not give me a clue.
2) Is there technical information available about how the Explorer board accesses the serial line of the TI CC1111 chip?
3) Will the newer version of the explorer board have support for linux 4.x kernels?

Because of this issue and because of issue https://github.com/EnhancedRadioDevices/915MHzEdisonExplorer/issues/16 I cannot use my Dexcom  G4 (connected to USB OTG, with power via UART) and communicatie with the TI CC1111 on the Explorer board to a WW insulin pump.

PieterGit, 2017-02-19:
I tested it with this distribution: https://github.com/atlury/Intel-Edison-OS-Images/releases and also manually upgraded to Linux 4.10rc's kernels. Both give the same errors accessing the TI-chip.

mogar, 2017-02-20:
The explorer board uses a CC1110, not a CC1111. There are a few differences to be aware of there; mainly that the CC1110 doesn't have USB.

Pin 23 is the mraa equivalent for the reset pin. Take a look at the schematic and you'll see that the reset pin of the CC1110 is connected to the GP14 on the Edison. Edison pin-numbering is a bit arcane, but the upshot is that mraa addresses that pin as number 23.

For technical information of the CC1110 connections on the explorer board, take a look at the schematic:
https://github.com/EnhancedRadioDevices/915MHzEdisonExplorer/blob/master/EdisonBlock_915MHz_fab/EdisonBlock_915MHz.pdf

That will show you what pins are connected where.

I'd say that the problems you're experiencing don't have anything to do with the hardware, and are instead software problems (potentially with mraa). Are you logging in as root? Mraa has some issues with non-root permissions.

PieterGit, 2017-02-20:
I thougth it was a CC1111. I'm running mraa as root. I'll look at the schematic docs and will try to communicate with a newer kernel using GPIO without mrra and using https://pypi.python.org/pypi/gpio/0.2.0 this library to see if that works.

PieterGit, 2017-02-20:
First attempt at https://github.com/scottleibrand/spi_serial/pull/1
I seem to be able to communicate with the CC1110 chip afacit (I get `Version: subg_rfspy 0.8` back from mmtune).

I can't get pump model or mmtune to work yet. Any help would be appreciated so that libmraa can be ditched on 4.10+ kernels. Trying with 4.10rc4 kernel (64 bits).

mogar, 2017-02-22:
Awesome stuff! It looks like you've managed to get your pump model back already, too.

It would be great to move away from libmraa in general. I'm pretty busy now, but I'm going to carve some time out early next month to look into that more.

andy-shev, 2021-10-04:
@mogar I'm wondering if there is any place where I can find pre-soldered Explorer board. I can enable and test the latest U-Boot and Linux kernel on it.

mogar, 2021-11-11:
Unfortunately, we're sold out. We haven't been keeping them in stock since the Edison went end-of-life.

scottleibrand, 2021-11-11:
Since you posted, the Pi Zero 2 has come out, which is much faster and more power-efficient, removing most of the downsides of building an Explorer HAT based rig. There is still some testing to be done to figure out which images are needed etc., which someone is working on...

andy-shev, 2021-11-11:
> There is still some testing to be done to figure out which images are needed etc., which someone is working on...
Yeah, right...

Meanwhile I am not looking for that solution.

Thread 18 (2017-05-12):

Change R11 value from 330 to 1.21k

jseaber, 2017-05-12:
R11 drives the Edison power LED, D6, consuming about 4mA, assuming a typical Vf of 2.1V for a red LED.

The LED is quite bright, so operating at lower current will improve battery run time (helpful for OpenAPS)! Most LEDs are still sufficiently bright at 1mA.

The same change could be applied to all LED resistors to maintain BOM simplicity (R1, R11, R9, R10).

scottleibrand, 2017-05-12:
I'm not sure how significant the battery life impact would be in real-world use, but regardless of that I think most of us running OpenAPS rigs at the bedside would prefer dimmer LEDs so we can more easily avoid light-in-the-face.  :-)

jdslabs, 2017-05-12:
Agreed! The LED currently lights up my wall at night.

Assuming 16 hours run time from a 2000mAH battery, saving 3mA*16 hrs = 48 mAh. It's a small amount, but should boost run time by 20min per charge.

mogar, 2017-05-15:
No problem. I'll talk to the manufacturer about this. Due to lead time on boards, it may take us up to two months to have boards with the higher resistance value.

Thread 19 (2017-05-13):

Explorer board stop to communicate

Diadon81, 2017-05-13:
I have Intel Edison and Explorer board.

Now my explorer board stop to communicate with my medtronic minimed 722. During the booting process I see the following error messages (please check an attachement). Could some one help me to understand what is happen with this board.

PS. I am using explorer board to communicate with my Medtronic Minimed 722 pump.

▒X▒▒▒▒▒▒▒▒▒▒▒▒▒▒▒▒▒▒▒▒▒▒▒▒▒▒▒▒▒▒▒Y▒▒jҐKERNEL VERSION: b0182929
WR: 20104000

SCU IPC: 0x800000d0 0xfffce92c

PSH miaHOB version: TNG.B0.VVBD.0000000c

microkernel built 10:14:01 Jan 13 2015

******* PSH loader *******
PCM page cache size = 192 KB
Cache Constraint = 0 Pages
Arming IPC driver ..
Adding page store pool ..
PagestoreAddr(IMR Start Address) = 0x04899000
pageStoreSize(IMR Size) = 0x00080000

*** Ready to receive application ***

U-Boot 2014.04 (Feb 09 2015 - 15:40:31)

   Watchdog enabled
DRAM: 980.6 MiB
MMC: tangier_sdhci: 0
In: serial
Out: serial
Err: serial
Hit any key to stop autoboot: 0
Target:blank
Partitioning already done...
Flashing already done...
GADGET DRIVER: usb_dnl_dfu
reading vmlinuz
5143872 bytes read in 128 ms (38.3 MiB/s)
Valid Boot Flag
Setup Size = 0x00003c00
Magic signature found
Using boot protocol version 2.0c
Linux kernel version 3.10.98-poky-edison (robin@robin-i7) #5 SMP PREEMPT Tue Apr 4 22:42:44 EDT 2017
Building boot_params at 0x00090000
Loading bzImage at address 00100000 (5128512 bytes)
Magic signature found
Kernel command line: "rootwait root=PARTUUID=012b3303-34ac-284d-99b4-34e03a2335f 4 rootfstype=ext4 console=ttyMFD2 earlyprintk=ttyMFD2,keep loglevel=4 g_multi.et hernet_config=rndis systemd.unit=multi-user.target hardware_id=00 g_multi.iSeria lNumber=b9d4eb860e4fe14df9e01d7b0f996106 g_multi.dev_addr=02:00:86:99:61:06"

Starting kernel ...

[ 0.000000] Zone ranges:
[ 0.000000] DMA [mem 0x00001000-0x00ffffff]
[ 0.000000] Normal [mem 0x01000000-0x377fdfff]
[ 0.000000] HighMem [mem 0x377fe000-0x3f4fffff]
[ 0.000000] Movable zone start for each node
[ 0.000000] Early memory node ranges
[ 0.000000] node 0: [mem 0x00001000-0x00097fff]
[ 0.000000] node 0: [mem 0x00100000-0x03ffffff]
[ 0.000000] node 0: [mem 0x06000000-0x3f4fffff]
[ 0.000000] Built 1 zonelists in Zone order, mobility grouping on. Total pag es: 249255
[ 0.213781] PCI: Probing PCI hardware
[ 0.656404] bounce pool size: 64 pages
[ 3.744522] Device: i2c-designware-pci
[ 3.744522] controller timed out
[ 3.744608] Modules linked in:
[ 3.744662] CPU: 0 PID: 1 Comm: swapper/0 Not tainted 3.10.98-poky-edison #5
[ 3.744729] Hardware name: Intel Corporation Merrifield/BODEGA BAY, BIOS 466 2014.06.23:19.20.05
[ 3.744807] f6889ab0 f6889ab0 f6889a78 c18b64f8 f6889aa0 c123e9ee c1b13ec0 f 6889acc
[ 3.744933] 000004d7 c1626520 c1626520 f5848c00 f6889b70 f5848c24 f6889ab8 c 123ea43
[ 3.745055] 00000009 f6889ab0 c1b13ec0 f6889acc f6889aec c1626520 c1b13ee4 0 00004d7
[ 3.745177] Call Trace:
[ 3.745229] [] dump_stack+0x16/0x18
[ 3.745294] [] warn_slowpath_common+0x5e/0x80
[ 3.745361] [] ? i2c_dw_xfer+0x1e0/0x5c0
[ 3.745422] [] ? i2c_dw_xfer+0x1e0/0x5c0
[ 3.745487] [] warn_slowpath_fmt+0x33/0x40
[ 3.745550] [] i2c_dw_xfer+0x1e0/0x5c0
[ 3.745617] [] _i2ctransfer+0x57/0x70
[ 3.745678] [] i2c_transfer+0x4d/0xc0
[ 3.745739] [] i2c_smbus_xfer+0x21a/0x600
[ 3.745815] [] ? idr_get_empty_slot+0x13f/0x370
[ 3.745883] [] i2c_smbus_read_word_data+0x3b/0x50
[ 3.745952] [] ? sub_preempt_count+0x3d/0x50
[ 3.746019] [] ? rawspin_unlock_irqrestore+0x26/0x50
[ 3.746089] [] ? devres_add+0x38/0x40
[ 3.746153] [] pca953x_read_regs.isra.5+0x2e/0xd0
[ 3.746223] [] ? _mutexinit+0x44/0x50
[ 3.746286] [] pca953x_probe+0x1b2/0x4b0
[ 3.746350] [] ? sysfs_do_create_link_sd+0xac/0x1d0
[ 3.746417] [] ? notifier_call_chain+0x41/0x60
[ 3.746486] [] ? _blockingnotifier_call_chain+0x44/0x60
[ 3.746562] [] i2c_device_probe+0x99/0x110
[ 3.746624] [] ? sysfs_create_link+0x22/0x40
[ 3.746690] [] ? pca953x_irq_handler+0x270/0x270
[ 3.746760] [] driver_probe_device+0x83/0x3a0
[ 3.746824] [] ? sub_preempt_count+0x3d/0x50
[ 3.746889] [] ? driver_probe_device+0x3a0/0x3a0
[ 3.746957] [] ? driver_probe_device+0x3a0/0x3a0
[ 3.747024] [] _deviceattach+0x31/0x40
[ 3.747086] [] bus_for_each_drv+0x47/0x80
[ 3.747150] [] device_attach+0x73/0x90
[ 3.747211] [] ? driver_probe_device+0x3a0/0x3a0
[ 3.747278] [] bus_probe_device+0x6f/0x90
[ 3.747341] [] device_add+0x5a5/0x680
[ 3.747402] [] ? complete_all+0x48/0x50
[ 3.747464] [] ? pm_runtime_init+0xcd/0xe0
[ 3.747528] [] device_register+0x17/0x20
[ 3.747589] [] i2c_new_device+0x128/0x1c0
[ 3.747654] [] ? class_compat_create_link+0x48/0x80
[ 3.747723] [] i2c_register_adapter+0x1d7/0x310
[ 3.747791] [] i2c_add_numbered_adapter+0x59/0x90
[ 3.747859] [] i2c_dw_setup+0x282/0x330
[ 3.747923] [] i2c_dw_pci_probe+0xa1/0x1d0
[ 3.747987] [] ? rawspin_unlock_irqrestore+0x26/0x50
[ 3.748063] [] pci_device_probe+0x6f/0xb0
[ 3.748128] [] driver_probe_device+0x83/0x3a0
[ 3.748196] [] _driverattach+0x71/0x80
[ 3.748258] [] ? _deviceattach+0x40/0x40
[ 3.748321] [] bus_for_each_dev+0x47/0x80
[ 3.748385] [] driver_attach+0x1e/0x20
[ 3.748445] [] ? _deviceattach+0x40/0x40
[ 3.748508] [] bus_add_driver+0x1cf/0x290
[ 3.748573] [] ? pci_pm_suspend+0x1b0/0x1b0
[ 3.748638] [] ? pci_pm_suspend+0x1b0/0x1b0
[ 3.748702] [] driver_register+0x6a/0x130
[ 3.748764] [] ? mutex_unlock+0xd/0x10
[ 3.748826] [] ? i2c_for_each_dev+0x38/0x50
[ 3.748892] [] ? i2c_gpio_init+0x2e/0x2e
[ 3.748956] [] _pciregister_driver+0x4a/0x50
[ 3.749022] [] dw_i2c_init_driver+0x14/0x16
[ 3.749085] [] do_one_initcall+0xaa/0x160
[ 3.749154] [] kernel_init_freeable+0x126/0x1bd
[ 3.749220] [] ? do_early_param+0x78/0x78
[ 3.749286] [] kernel_init+0x10/0x140
[ 3.749346] [] ret_from_kernel_thread+0x1b/0x28
[ 3.749412] [] ? rest_init+0x80/0x80
[ 3.749514] i2c-designware-pci 0000:00:08.0: ===== REGISTER DUMP (i2c) =====
[ 3.749586] i2c-designware-pci 0000:00:08.0: DW_IC_CON: 0x65
[ 3.749655] i2c-designware-pci 0000:00:08.0: DW_IC_TAR: 0x20
[ 3.749724] i2c-designware-pci 0000:00:08.0: DW_IC_SS_SCL_HCNT: 0x2f8
[ 3.749794] i2c-designware-pci 0000:00:08.0: DW_IC_SS_SCL_LCNT: 0x37b
[ 3.749863] i2c-designware-pci 0000:00:08.0: DW_IC_FS_SCL_HCNT: 0x87
[ 3.749932] i2c-designware-pci 0000:00:08.0: DW_IC_FS_SCL_LCNT: 0x10a
[ 3.750002] i2c-designware-pci 0000:00:08.0: DW_IC_INTR_STAT: 0x0
[ 3.750070] i2c-designware-pci 0000:00:08.0: DW_IC_INTR_MASK: 0x246
[ 3.750139] i2c-designware-pci 0000:00:08.0: DW_IC_RAW_INTR_STAT: 0x10
[ 3.750207] i2c-designware-pci 0000:00:08.0: DW_IC_RX_TL: 0x20
[ 3.750276] i2c-designware-pci 0000:00:08.0: DW_IC_TX_TL: 0x20
[ 3.750345] i2c-designware-pci 0000:00:08.0: DW_IC_ENABLE: 0x1
[ 3.750412] i2c-designware-pci 0000:00:08.0: DW_IC_STATUS: 0x2
[ 3.750480] i2c-designware-pci 0000:00:08.0: DW_IC_TXFLR: 0x3
[ 3.750548] i2c-designware-pci 0000:00:08.0: DW_IC_RXFLR: 0x0
[ 3.750616] i2c-designware-pci 0000:00:08.0: DW_IC_TX_ABRT_SOURCE: 0x0
[ 3.750684] i2c-designware-pci 0000:00:08.0: DW_IC_DATA_CMD: 0x0
[ 3.750751] i2c-designware-pci 0000:00:08.0: ===============================
[ 3.750851] CPU: 0 PID: 1 Comm: swapper/0 Tainted: G W 3.10.98-poky -edison #5
[ 3.750856] Hardware name: Intel Corporation Merrifield/BODEGA BAY, BIOS 466 2014.06.23:19.20.05
[ 3.750863] task: f6880000 ti: f6888000 task.ti: f6888000
[ 3.750871] EIP: 0060:[] EFLAGS: 00000206 CPU: 0
[ 3.750883] EIP is at default_send_IPI_mask_logical+0x8b/0xd0
[ 3.750890] EAX: 00000000 EBX: 03000000 ECX: c1b926a0 EDX: fffff000
[ 3.750897] ESI: 00000206 EDI: 00000002 EBP: f6889a9c ESP: f6889a8c
[ 3.750904] DS: 007b ES: 007b FS: 00d8 GS: 0000 SS: 0068
[ 3.750910] CR0: 8005003b CR2: 00000000 CR3: 01ccd000 CR4: 001007f0
[ 3.750916] DR0: 00000000 DR1: 00000000 DR2: 00000000 DR3: 00000000
[ 3.750920] DR6: ffff0ff0 DR7: 00000400
[ 3.750923] Stack:
[ 3.750946] 00000800 00002710 f6889b70 f5848c24 f6889aa8 c12215c0 00002710 f 6889ab8
[ 3.750967] c122172c c1aa2493 f5848c00 f6889aec c1626788 f60e9064 c1abd8fc 0 0000000
[ 3.750987] c1af17cf 00000000 f5848c98 00000002 f6889af4 f5848c98 00000000 c 1bda628
[ 3.750990] Call Trace:
[ 3.751007] [] default_send_IPI_all+0x60/0x70
[ 3.751021] [] arch_trigger_all_cpu_backtrace+0x4c/0x80
[ 3.751034] [] i2c_dw_xfer+0x448/0x5c0
[ 3.751050] [] _i2ctransfer+0x57/0x70
[ 3.751062] [] i2c_transfer+0x4d/0xc0
[ 3.751075] [] i2c_smbus_xfer+0x21a/0x600
[ 3.751095] [] ? idr_get_empty_slot+0x13f/0x370
[ 3.751108] [] i2c_smbus_read_word_data+0x3b/0x50
[ 3.751121] [] ? sub_preempt_count+0x3d/0x50
[ 3.751135] [] ? rawspin_unlock_irqrestore+0x26/0x50
[ 3.751146] [] ? devres_add+0x38/0x40
[ 3.751161] [] pca953x_read_regs.isra.5+0x2e/0xd0
[ 3.751174] [] ? _mutexinit+0x44/0x50
[ 3.751187] [] pca953x_probe+0x1b2/0x4b0
[ 3.751200] [] ? sysfs_do_create_link_sd+0xac/0x1d0
[ 3.751211] [] ? notifier_call_chain+0x41/0x60
[ 3.751226] [] ? _blockingnotifier_call_chain+0x44/0x60
[ 3.751241] [] i2c_device_probe+0x99/0x110
[ 3.751253] [] ? sysfs_create_link+0x22/0x40
[ 3.751267] [] ? pca953x_irq_handler+0x270/0x270
[ 3.751281] [] driver_probe_device+0x83/0x3a0
[ 3.751293] [] ? sub_preempt_count+0x3d/0x50
[ 3.751306] [] ? driver_probe_device+0x3a0/0x3a0
[ 3.751320] [] ? driver_probe_device+0x3a0/0x3a0
[ 3.751332] [] _deviceattach+0x31/0x40
[ 3.751345] [] bus_for_each_drv+0x47/0x80
[ 3.751358] [] device_attach+0x73/0x90
[ 3.751371] [] ? driver_probe_device+0x3a0/0x3a0
[ 3.751384] [] bus_probe_device+0x6f/0x90
[ 3.751396] [] device_add+0x5a5/0x680
[ 3.751409] [] ? complete_all+0x48/0x50
[ 3.751421] [] ? pm_runtime_init+0xcd/0xe0
[ 3.751434] [] device_register+0x17/0x20
[ 3.751445] [] i2c_new_device+0x128/0x1c0
[ 3.751460] [] ? class_compat_create_link+0x48/0x80
[ 3.751473] [] i2c_register_adapter+0x1d7/0x310
[ 3.751485] [] i2c_add_numbered_adapter+0x59/0x90
[ 3.751498] [] i2c_dw_setup+0x282/0x330
[ 3.751512] [] i2c_dw_pci_probe+0xa1/0x1d0
[ 3.751526] [] ? rawspin_unlock_irqrestore+0x26/0x50
[ 3.751542] [] pci_device_probe+0x6f/0xb0
[ 3.751556] [] driver_probe_device+0x83/0x3a0
[ 3.751571] [] _driverattach+0x71/0x80
[ 3.751584] [] ? _deviceattach+0x40/0x40
[ 3.751596] [] bus_for_each_dev+0x47/0x80
[ 3.751609] [] driver_attach+0x1e/0x20
[ 3.751621] [] ? _deviceattach+0x40/0x40
[ 3.751634] [] bus_add_driver+0x1cf/0x290
[ 3.751648] [] ? pci_pm_suspend+0x1b0/0x1b0
[ 3.751662] [] ? pci_pm_suspend+0x1b0/0x1b0
[ 3.751675] [] driver_register+0x6a/0x130
[ 3.751687] [] ? mutex_unlock+0xd/0x10
[ 3.751701] [] ? i2c_for_each_dev+0x38/0x50
[ 3.751715] [] ? i2c_gpio_init+0x2e/0x2e
[ 3.751729] [] _pciregister_driver+0x4a/0x50
[ 3.751742] [] dw_i2c_init_driver+0x14/0x16
[ 3.751753] [] do_one_initcall+0xaa/0x160
[ 3.751769] [] kernel_init_freeable+0x126/0x1bd
[ 3.751782] [] ? do_early_param+0x78/0x78
[ 3.751796] [] kernel_init+0x10/0x140
[ 3.751808] [] ret_from_kernel_thread+0x1b/0x28
[ 3.751820] [] ? rest_init+0x80/0x80
[ 3.751937] Code: b3 ff ff 89 f8 09 d0 80 ce 04 83 ff 02 0f 44 c2 8b 15 94 2b b9 c1 89 82 00 b3 ff ff f7 c6 00 02 00 00 74 14 e8 57 03 0b 00 56 9d <83> c4 04 5b 5e 5f 5d c3 90 8d 74 26 00 56 9d e8 41 ff 0a 00 83
[ 3.751958] CPU: 1 PID: 0 Comm: swapper/1 Tainted: G W 3.10.98-poky -edison #5
[ 3.751963] Hardware name: Intel Corporation Merrifield/BODEGA BAY, BIOS 466 2014.06.23:19.20.05
[ 3.751971] task: f6883de0 ti: f6a1e000 task.ti: f6a1e000
[ 3.751979] EIP: 0060:[] EFLAGS: 00200286 CPU: 1
[ 3.751993] EIP is at default_idle+0x22/0xf0
[ 3.752000] EAX: 00000000 EBX: 02100800 ECX: 00000000 EDX: 00000000
[ 3.752006] ESI: 00000000 EDI: 00000001 EBP: f6a1ff70 ESP: f6a1ff64
[ 3.752013] DS: 007b ES: 007b FS: 00d8 GS: 0000 SS: 0068
[ 3.752019] CR0: 8005003b CR2: 00000000 CR3: 01ccd000 CR4: 001007f0
[ 3.752025] DR0: 00000000 DR1: 00000000 DR2: 00000000 DR3: 00000000
[ 3.752029] DR6: ffff0ff0 DR7: 00000400
[ 3.752032] Stack:
[ 3.752056] 02100800 00000000 f6a1e000 f6a1ff78 c12081a6 f6a1ff94 c1284577 f fffffff
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
scottleibrand, 2017-05-13:
I don't see any errors there. Have you already joined https://gitter.im/nightscout/intend-to-bolus for troubleshooting help?

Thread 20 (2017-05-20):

Suggestion re red LED on Explorer board - the "in operation" LED, NOT the charging LED

mhaeberli, 2017-05-20:
Thanks for the Explorers!

If possible, I'd like to suggest for future Explorer boards that the red LED that shows the Explorer/Edison is on and functioning be changed to an RGB LED so that the Edison firmware could show additional status using LED color.  For example, in an openaps application, green could mean "all is working, loop is running"...

mogar, 2017-05-20:
The red LED is only connected to power, and is on whenever there is power to the board.

There are also two User LEDs that can be controlled from the Edison programatically. One is red, and one with green. You can hook those into whatever functionality you want in software, thought that will lead to a slight decrease in battery life to have them on rather than off.

mhaeberli, 2017-05-20:
Hi!
Where can I find hints on the two user LEDs?
Suggest / request RGB LEDs for future?
Best,
Martin

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

scottleibrand, 2017-05-20:
LED control is done in the subg_rfspy firmware.

mhaeberli, 2017-05-20:
Scott - thx, but is there any simple API to fiddle LEDs from the openaps code, like for example some kind of python bindings?  Or would I have to build custom subg_rfspy firmware to this end (referring to the red and green LEDs mentioned)?  I don't want to upset the rest of the delicate balance...

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

scottleibrand, 2017-05-20:
Nope. Someone would have to build that into subg_rfspy.

mhaeberli, 2017-05-20:
ok, thx

On Sat, May 20, 2017 at 2:53 PM, Scott Leibrand <notifications@github.com>
wrote:

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

mogar, 2017-05-20:
It is built into subg_rfspy. There is a simple command to turn LEDs on or
off. Check out the examples in that repo.

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

mhaeberli, 2017-05-20:
thx!

On Sat, May 20, 2017 at 3:41 PM, Morgan Redfield <notifications@github.com>
wrote:

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

Closed 2018-03-08.

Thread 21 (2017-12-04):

C10/C14 Capacitors

infoneo, 2017-12-04:
Do the C10/C14 capacitors shouldn't be about 31pF   =2*(18pF-2,5pF)
According to CC1110 datasheet - "9.3 Crystal"

mogar, 2018-03-08:
After thinking about a bit more, I see what you're asking. Yes, 31pF capacitors would get us close to the nominal values for our crystal. You're right about that. The oscillator functions as is, so we're going to leave it.

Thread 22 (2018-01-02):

Micro USB connectors broke of

PieterGit, 2018-01-02:
I wrote a guide how to fix the Explorer board if the micro usb connectors came off.
If others have success or failed, please use this issue.

PieterGit, 2018-01-03:
Pull request for oref0 docs can be found here: https://github.com/openaps/docs/pull/1193

While the PR has not been merged, a rendered version can be found here: https://github.com/PieterGit/docs/blob/201801_microusb/docs/docs/Troubleshooting/Edison-hardware-troubleshooting.md

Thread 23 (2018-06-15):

Blinking power light/ Damaged JST?

rainbow-lazer, 2018-06-15:
Hello, I recently got a new lipo battery for my board, the JST connector of which got stuck in the port. I had to pull it out (as gently as possible) with pliers.

After soldering on a new JST, my board's power light (D6) and one of the radio lights (D2), blink on and off, and the board doesn't seem to boot off the battery anymore. Here's a video: [https://www.dropbox.com/s/ttkknapebdbdmxr/2018-06-15%2014.51.54.mov?dl=0](https://www.dropbox.com/s/ttkknapebdbdmxr/2018-06-15%2014.51.54.mov?dl=0)

When I connect via USB, the lights work as usual and it boots fine. The receiving power port on the board looks just fine, I don't see any bent pins or cracked solder; is there any other way to troubleshoot what's going on with my JST power?

Thanks!

rainbow-lazer, 2018-06-15:
ps, just to troubleshoot, I used a multimeter on the repaired battery and it is giving 3.7v. I also tried the battery from my backup board (which I know works), and still get the same blinking lights.

mogar, 2018-07-03:
Can you email us at sales@enhancedradio.com? We can work on this issue there.

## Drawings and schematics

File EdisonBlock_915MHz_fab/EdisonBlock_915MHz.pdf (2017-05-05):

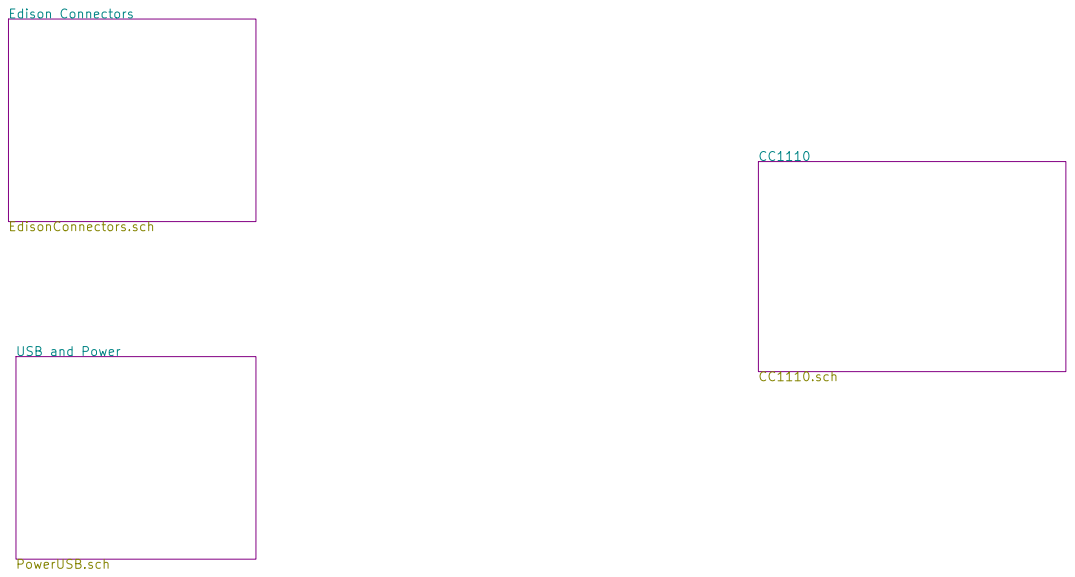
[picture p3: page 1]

File: EdisonBlock_915MHz.sch Sheet: / Enhanced Radio Devices, LLC.

Id: 1/4 Title: Edison Block - 915MHz Radio Adapter

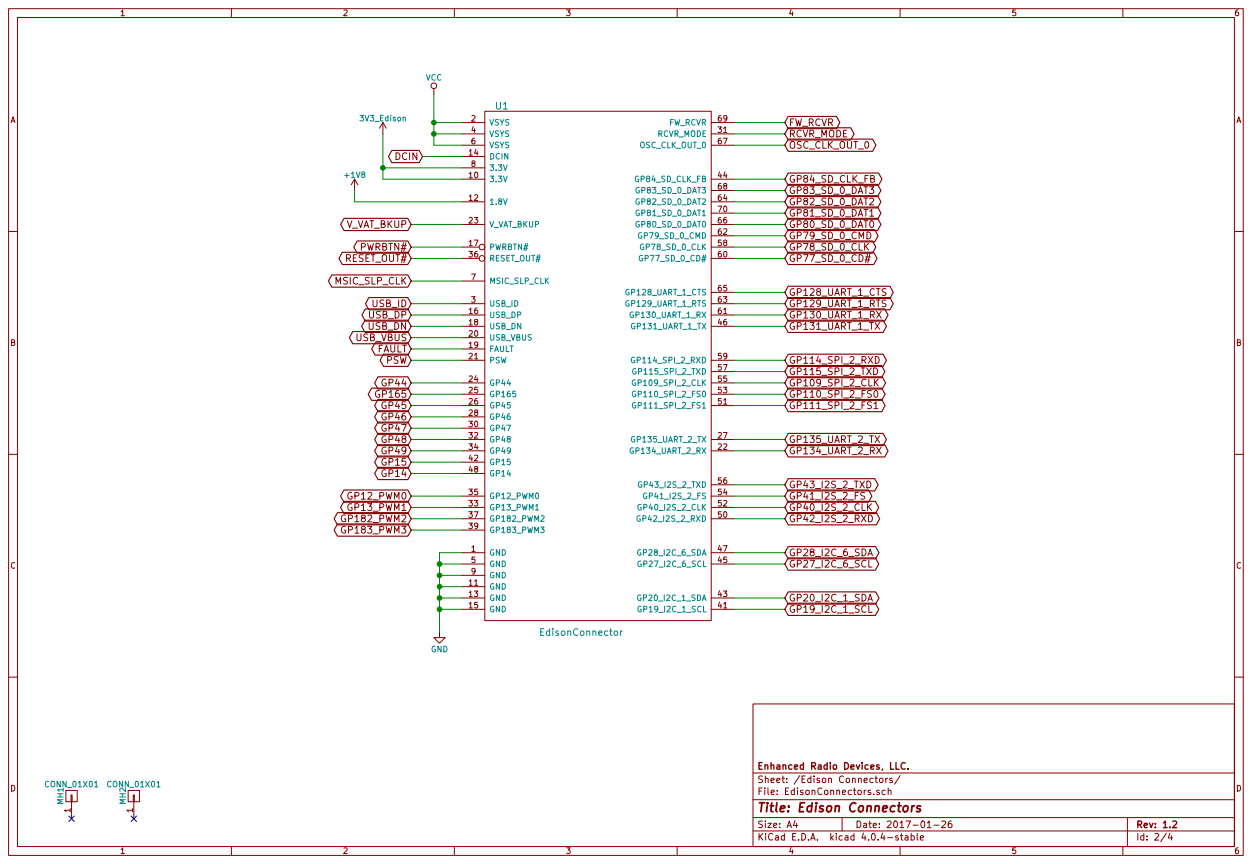
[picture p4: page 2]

File: EdisonConnectors.sch Sheet: /Edison Connectors/ Enhanced Radio Devices, LLC. GND 1

Id: 2/4 Title: Edison Connectors

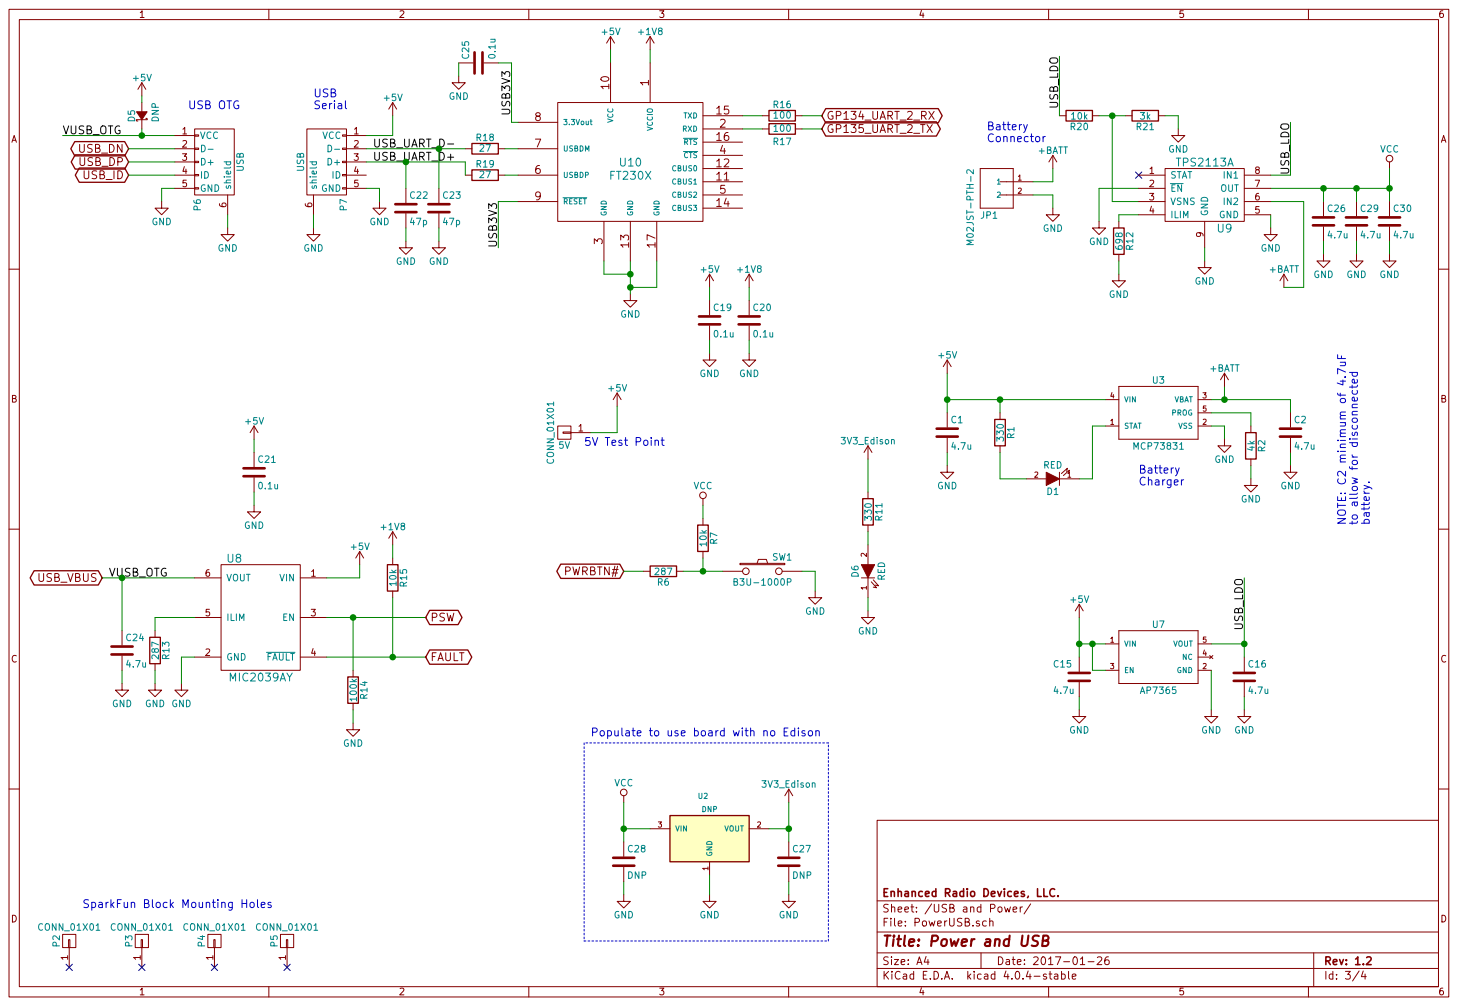
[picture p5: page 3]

1 P5 CONN_01X01 SparkFun Block Mounting Holes GND GND

3V3_Edison Populate to use board with no Edison

File: PowerUSB.sch Sheet: /USB and Power/ Enhanced Radio Devices, LLC.

Id: 3/4 Title: Power and USB

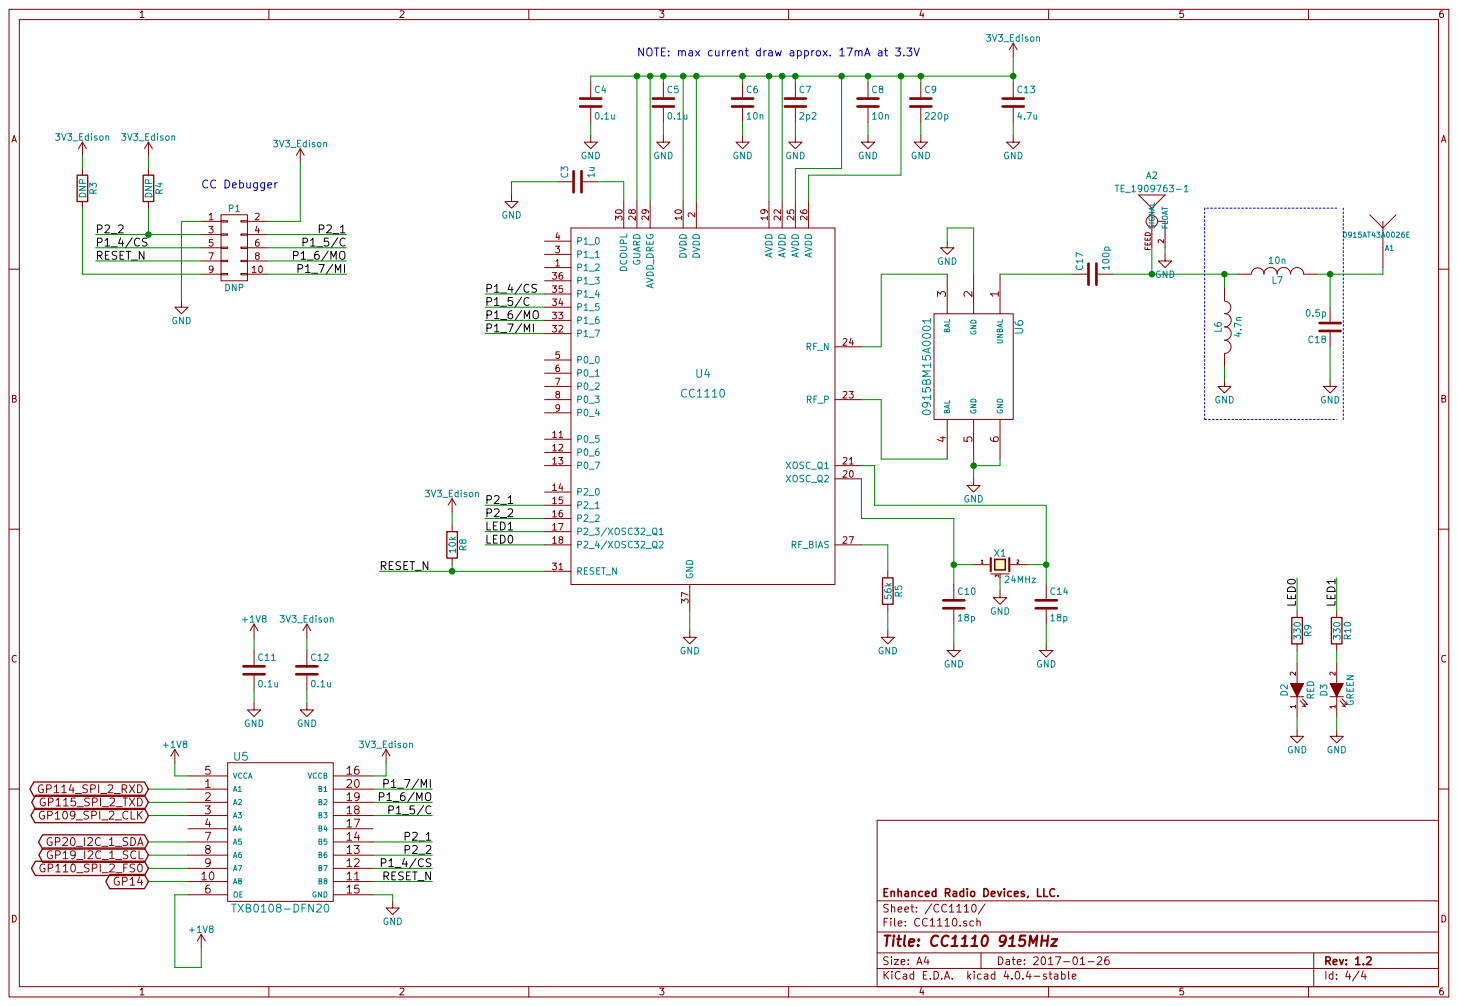
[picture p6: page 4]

NOTE: max current draw approx. 17mA at 3.3V

2 P1_1 3 P1_0 4 P0_0 5 P0_1 6 P0_2 7 P0_3 8 P0_4 9 DVDD 10 XOSC_Q2 20 DCOUPL 30 P0_5 11 XOSC_Q1 21 RESET_N 31 P0_6 12 AVDD 22 P1_7 32 P0_7 13 RF_P 23 P1_6 33 P2_0 14 RF_N 24 P1_5 34 P2_1 15 AVDD 25 P1_4 35 P2_2 16 AVDD 26 P1_3 36 P2_3/XOSC32_Q1 17 RF_BIAS 27 GND 37 P2_4/XOSC32_Q2 18 GUARD 28 AVDD 19 AVDD_DREG 29 U4 CC1110 GND GND GND GND GND GND GND GND

File: CC1110.sch Sheet: /CC1110/ Enhanced Radio Devices, LLC.

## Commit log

2016-08-26 first commit, working hardware
    [Battery.sch, CC1110.sch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]
2016-09-21 bug fixes: UART, power, R4
    [CC1110.sch, EdisonBlock_915MHz.kicad_pcb, PowerUSB.sch]
2016-09-21 swap switch for reset button
    [CC1110.sch, EdisonBlock_915MHz.kicad_pcb, EdisonConnectors.sch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]
2016-09-30 update 915Ant conn
    [CC1110.sch, EdisonBlock_915MHz.kicad_pcb, EdisonConnectors.sch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]
2016-10-01 update part number for rf jack
    [CC1110.sch]
2016-10-01 draft layout, fix footprints
    [CC1110.sch, EdisonBlock_915MHz.kicad_pcb, EdisonBlock_915MHz_mfg_BoM.xlsx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]
2016-12-01 pre-order boards
    [Battery.sch, CC1110.sch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]
2016-12-01 update wrl thickness
    [EdisonBlock_915MHz.kicad_pcb]
2017-05-05 current mfg version
    [CC1110.sch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]
2017-05-05 mfg revision
    [CC1110.sch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]
2017-05-06 fix library issues
    [CC1110.sch, EdisonBlock_915MHz.kicad_pcb, PowerUSB.sch]
2021-11-09 Update README.md
    https://forum.kicad.info/t/warning-avoid-all-links-to-kicad-pcb-org-use-kicad-org/31521
